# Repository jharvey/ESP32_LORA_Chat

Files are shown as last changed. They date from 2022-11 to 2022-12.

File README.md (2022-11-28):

# ESP32_LORA_Chat </br>
Redesign of Armachat hardware using KICAD and JLCPCB </br>
<hr />
The orginal Armachat from Peter Misenko's work at [bobricius/Armachat-circuitpython](https://github.com/bobricius/Armachat-circuitpython).</br>
This is a ESP32 with working EInk display project, which may be a useful reference https://github.com/Uspizig/EinkKeyboard</br>
 </br>
This is a redesign of bobricius/Armachat hardware to include: </br>
- ESP32 core processor </br>
- E-Ink display for lower power consumpiton </br>
- LORA communications </br>
- 18650 battery </br>
- KICAD </br>
 </br>
 
 front | back | PCB
--- | --- | ---
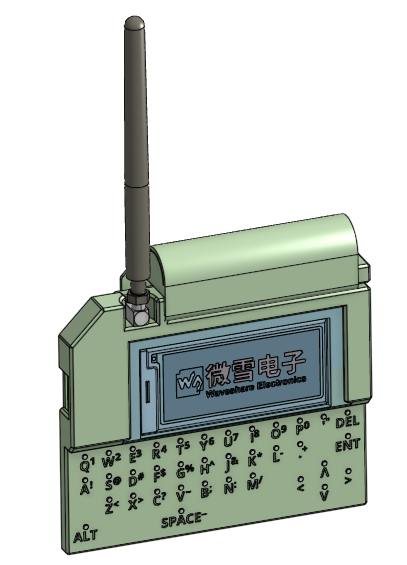
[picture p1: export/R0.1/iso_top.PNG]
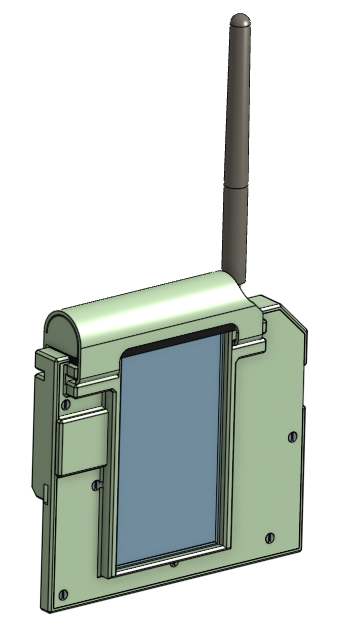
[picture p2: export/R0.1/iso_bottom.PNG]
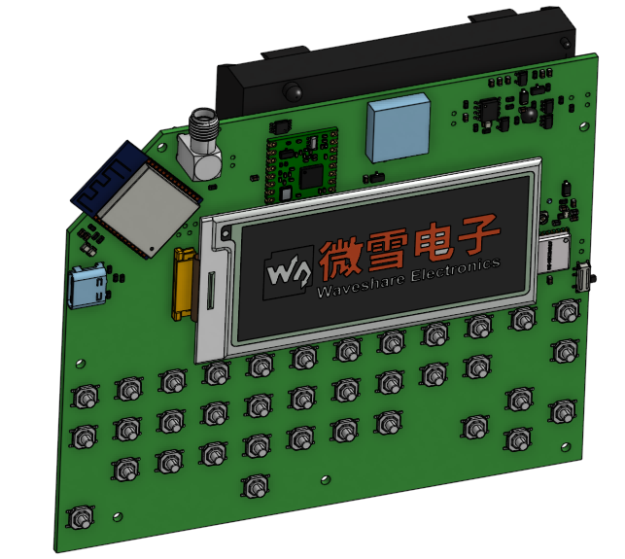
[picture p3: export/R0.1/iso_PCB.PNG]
 |  | 
 </br>
3D model for enclosure found here </br>
https://cad.onshape.com/documents/2eca9b71ceb843e60ebed659/w/deaed59ddef0917efb45d1fe/e/0c98206fb1ddff68e078d781

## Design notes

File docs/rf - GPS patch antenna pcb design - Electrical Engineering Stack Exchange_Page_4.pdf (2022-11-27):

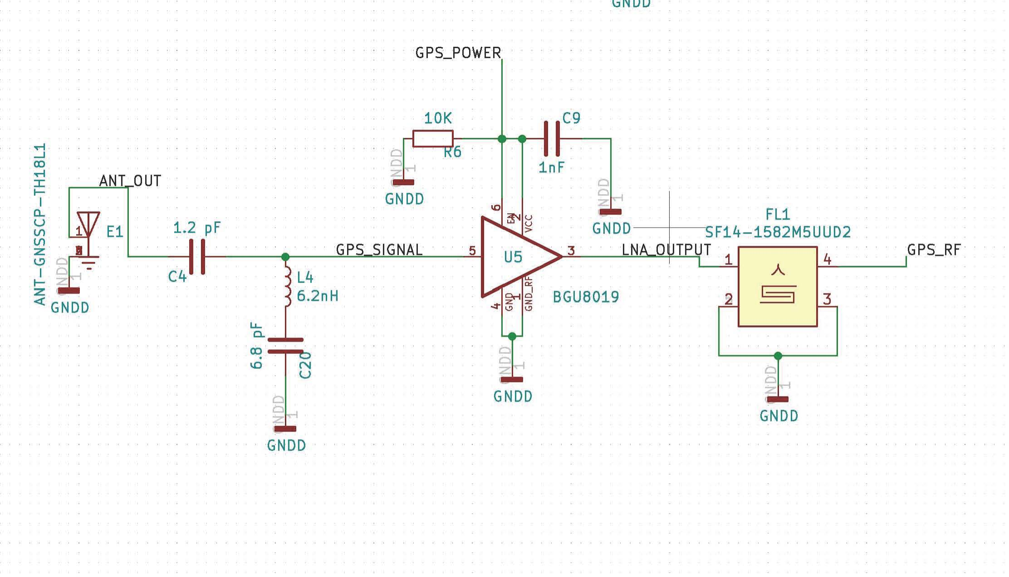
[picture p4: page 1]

..-i
--'
to
..-i
:r:
l-

ANT OUT
I
a..
u
1Il
1Il
Z
<.!l

~7 E1 ....=.c

I
I-
z

I
° -

<G NDD

1.2 pF

C4

'-'-
D..
. . | to .
| <D

GPS POWER -

10K
rl . b 1"<6

0..-i

## ii .. GNDD

'"
r-....~ u
u
>
GPS SIGNAL | 5 | U5
L4
~~ ~
6.2nH | J ... :3 | z
'"

b
N
U | t b | GNDD

t GNDD

lo ~ UU

C9

1nF

0
oM
ii .. | FL1
GNDD | SF14-15B2M5UUD2
:3 | LNA 0 UTPUT 1 | 4 | I A
BGUB019 | ~ | I | I | rl-

b
b.,-i
ii. GNDD

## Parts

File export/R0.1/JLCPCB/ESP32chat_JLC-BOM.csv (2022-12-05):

Comment | Designator | Footprint | LCSC
Antenna | AE1 | KICAD_Footprints:KH-GPS181804-WY | C962215
Conn_Coaxial | AE2 | Connector_Coaxial:U.FL_Hirose_U.FL-R-SMT-1_Vertical | C88374
18650 | BT1 | Battery:BatteryHolder_Keystone_1042_1x18650 | C2988620
1u | C1,C3,C6,C10,C15,C22,C23,C25,C26,C27,C28,C29,C30,C31,C32,C38 | Capacitor_SMD:C_0603_1608Metric | C15849
1.2p | C14 | Capacitor_SMD:C_0603_1608Metric | C281768
6.8p | C16 | Capacitor_SMD:C_0603_1608Metric | C1679
1n | C18 | Capacitor_SMD:C_0603_1608Metric | C100040
100n | C2,C8,C11,C13,C17,C21,C24,C33,C37 | Capacitor_SMD:C_0603_1608Metric | C14663
4.7uF | C20,C34 | Capacitor_SMD:C_0603_1608Metric | C162274
220n | C35 | Capacitor_SMD:C_0603_1608Metric | C21120
10u | C4,C5,C7,C9,C12,C19,C36 | Capacitor_SMD:C_0603_1608Metric | C194427
MBR0530 | D1,D2,D3,D4,D5 | Diode_SMD:D_SOD-123 | C77336
TA1661A | FL1 | KICAD_Footprints:TA1661A | C2961690
GRN | GRN1 | LED_SMD:LED_0805_2012Metric | C434432
CONN_021X02_NO_SILK | J1,J2,J3,J6,J7,J9 | Connector_PinHeader_2.54mm:PinHeader_1x02_P2.54mm_Vertical | DNP
CONN_01 | J4,J5 | Connector_Wire:SolderWirePad_1x01_SMD_5x10mm | DNP
Micro_SD_Card_Det | J8 | KICAD_Footprints:microSD_HC_Molex_104031-0811_Modified_for_JLCPCB | C585350
6.2nH | L1 | Inductor_SMD:L_0603_1608Metric | C98083
68uh | L2 | Inductor_SMD:L_Coilcraft_XAL60xx_6.36x6.56mm | C9393
6.8nH | L3 | Inductor_SMD:L_0603_1608Metric | C316305
SYM_Radio_Waves_Small | LOGO1 | Symbol:ESD-Logo_6.6x6mm_SilkScreen | C108781
OSHW-LOGOS | LOGO2 | Symbol:OSHW-Logo2_7.3x6mm_Copper | DNP
ORG | ORG1 | LED_SMD:LED_0805_2012Metric | C84262
Q_PMOS_DGS | Q1 | KICAD_Footprints:SOT-23_Modified_for_JLCPCB | C15127
BSS123 | Q2 | KICAD_Footprints:SOT-23_Modified_for_JLCPCB | C79015
Si1308 | Q3 | KICAD_Footprints:SOT-323_SC-70_Modified_for_JLCPCB | C469327
Q_NPN_BEC | Q4,Q5 | KICAD_Footprints:SOT-23_Modified_for_JLCPCB | C49581
10K | R1,R2,R3,R4,R7,R9,R12,R14,R18,R34,R35,R43,R44 | Resistor_SMD:R_0603_1608Metric | C25804
0R | R10,R15,R16,R20,R21,R25,R26,R27,R28,R29,R30,R31,R32,R33,R36,R37,R39,R40,R41,R42 | Resistor_SMD:R_0603_1608Metric | C21189
100 | R11 | Resistor_SMD:R_0603_1608Metric | C4184
50K | R13,R17 | Resistor_SMD:R_0603_1608Metric | C23162
1K5 | R23,R24 | Resistor_SMD:R_0603_1608Metric | C22843
0R47 | R38 | Resistor_SMD:R_0603_1608Metric | C23411
10K DNP | R45 | Resistor_SMD:R_0603_1608Metric | DNP
22K1 | R47,R48 | Resistor_SMD:R_0603_1608Metric | C3016734
0R | R49,R51,R52 | Resistor_SMD:R_2010_5025Metric | C2907556
5K1 | R5,R19,R50 | Resistor_SMD:R_0603_1608Metric | C23186
1K | R6,R8,R22,R46,R53 | Resistor_SMD:R_0603_1608Metric | C21190
RED | RED1 | LED_SMD:LED_0805_2012Metric | C84256
PB22 | S1,S2,S3,S4,S5,S6,S7,S8,S9,S10,S11,S12,S13,S14,S15,S16,S17,S18,S19,S20,S21,S22,S23,S24,S25,S26,S27,S28,S29,S30,S31,S32,S33,S34,S35,S36 | KICAD_Footprints:TS-1187A-C-G-B | C318886
Solar_Cell | SC1 |  | DNP
SW_DIP_x01 | SW1 | Button_Switch_SMD:SW_SPDT_PCM12 | C109335
SW_Push_DPDT | SW2 | Button_Switch_THT:SW_E-Switch_EG1271_DPDT | C136144
CONN_01 | TP1,TP2,TP3,TP4,TP5,TP6,TP7,TP8,TP9,TP10,TP11,TP12,TP13,TP14,TP15,TP16,TP17,TP18,TP19,TP20,TP21,TP22,TP23,TP24,TP25,TP26,TP27,TP28,TP29,TP30,TP31,TP32,TP33,TP34,TP35,TP36,TP37,TP38,TP39,TP40,TP41,TP42,TP43,TP44,TP45,TP46 | KICAD_Footprints:TST_x01_P2.54mm_Vertical | DNP
MCP73831T-2ACI/OT | U1 | KICAD_Footprints:SOT-23-5_Modified_for_JLCPCB-5 | C424093
MOUNTINGHOLE2.0 | U10,U11,U12,U13,U14,U15,U16,U17 | MountingHole:MountingHole_2.2mm_M2_DIN965_Pad | DNP
BGU8019 | U18 | KICAD_Footprints:XSON6 | C3190009
BUZZER | U19 | KICAD_Footprints:FS-1340 | C482342
TP4056 | U2 | KICAD_Footprints:SOIC-8-1EP_3.9x4.9mm_P1.27mm_EP2.29x3mm_Therm_Modified_for_JLCPCB | C16581
LM75B | U20 | KICAD_Footprints:MSOP-8_3x3mm_P0.65mm_Modified_for_JLCPCB | C2837470
ATGM336H-5N31 | U21 | KICAD_Footprints:ATGM336H-5N | C90770
QMC5883L | U22 | Package_LGA:LGA-16_3x3mm_P0.5mm | C976032
FPCConn | U23 | KICAD_Footprints:TE_2-1734839-4_1x24-1MP_P0.5mm_Horizontal_2 | C11092
CP2102N-Axx-xQFN28 | U24 | Package_DFN_QFN:QFN-28-1EP_5x5mm_P0.5mm_EP3.35x3.35mm | C964632
ESP32 | U3 | KICAD_Footprints:ESP32-S3-WROOM-1 | C2913204
FS8205A | U4 | KICAD_Footprints:TSSOP-8_4.4x3mm_P0.65mm_Modified_for_JLCPCB | C16052
DW01 | U5 | KICAD_Footprints:SOT-23-6_Modified_for_JLCPCB | C351410
RT9013 | U6 | KICAD_Footprints:SOT-23-5_Modified_for_JLCPCB | C47773
RFM69HCW | U7 | KICAD_Footprints:RFM69HCW | C2844473
tp4056_KoreanHropartsElecTYPE-C-31-M-12 | U8,U25 | KICAD_Footprints:USB-C_SMD-TYPE-C-31-M-12 | C134092
PCA9555PW | U9 | KICAD_Footprints:TSSOP-24_4.4x7.8mm_P0.65mm_Modified_for_JLCPCB | C128392
uFL | X1 | KICAD_Footprints:SMA_Molex_73251-2200_Horizontal_Modified_for_JLCPCB | C411575

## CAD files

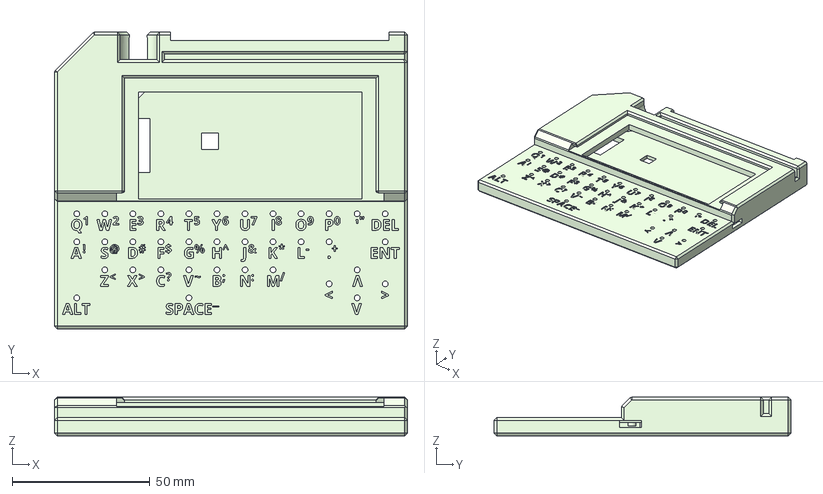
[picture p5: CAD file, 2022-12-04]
export/R0.1/JLCPCB/top_enclosure.step
127.9 x 107.6 x 14.1 mm

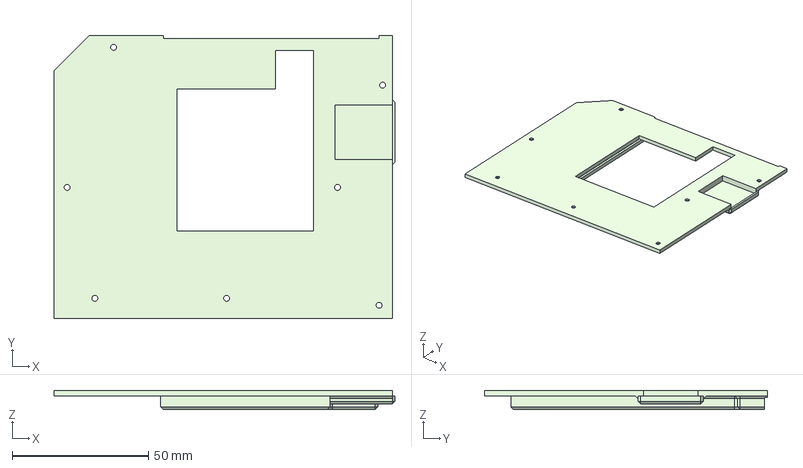
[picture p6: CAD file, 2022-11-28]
export/R0.1/JLCPCB/bottom_enclosure.step
124.9 x 103.6 x 7.00 mm

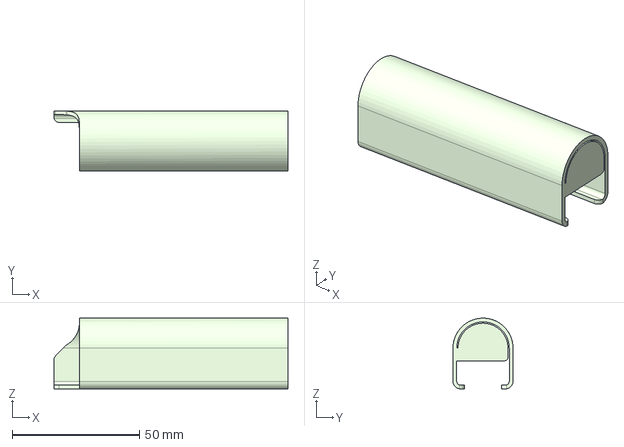
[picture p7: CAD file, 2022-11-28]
export/R0.1/JLCPCB/Bat_Cover.step
92.0 x 23.7 x 27.8 mm

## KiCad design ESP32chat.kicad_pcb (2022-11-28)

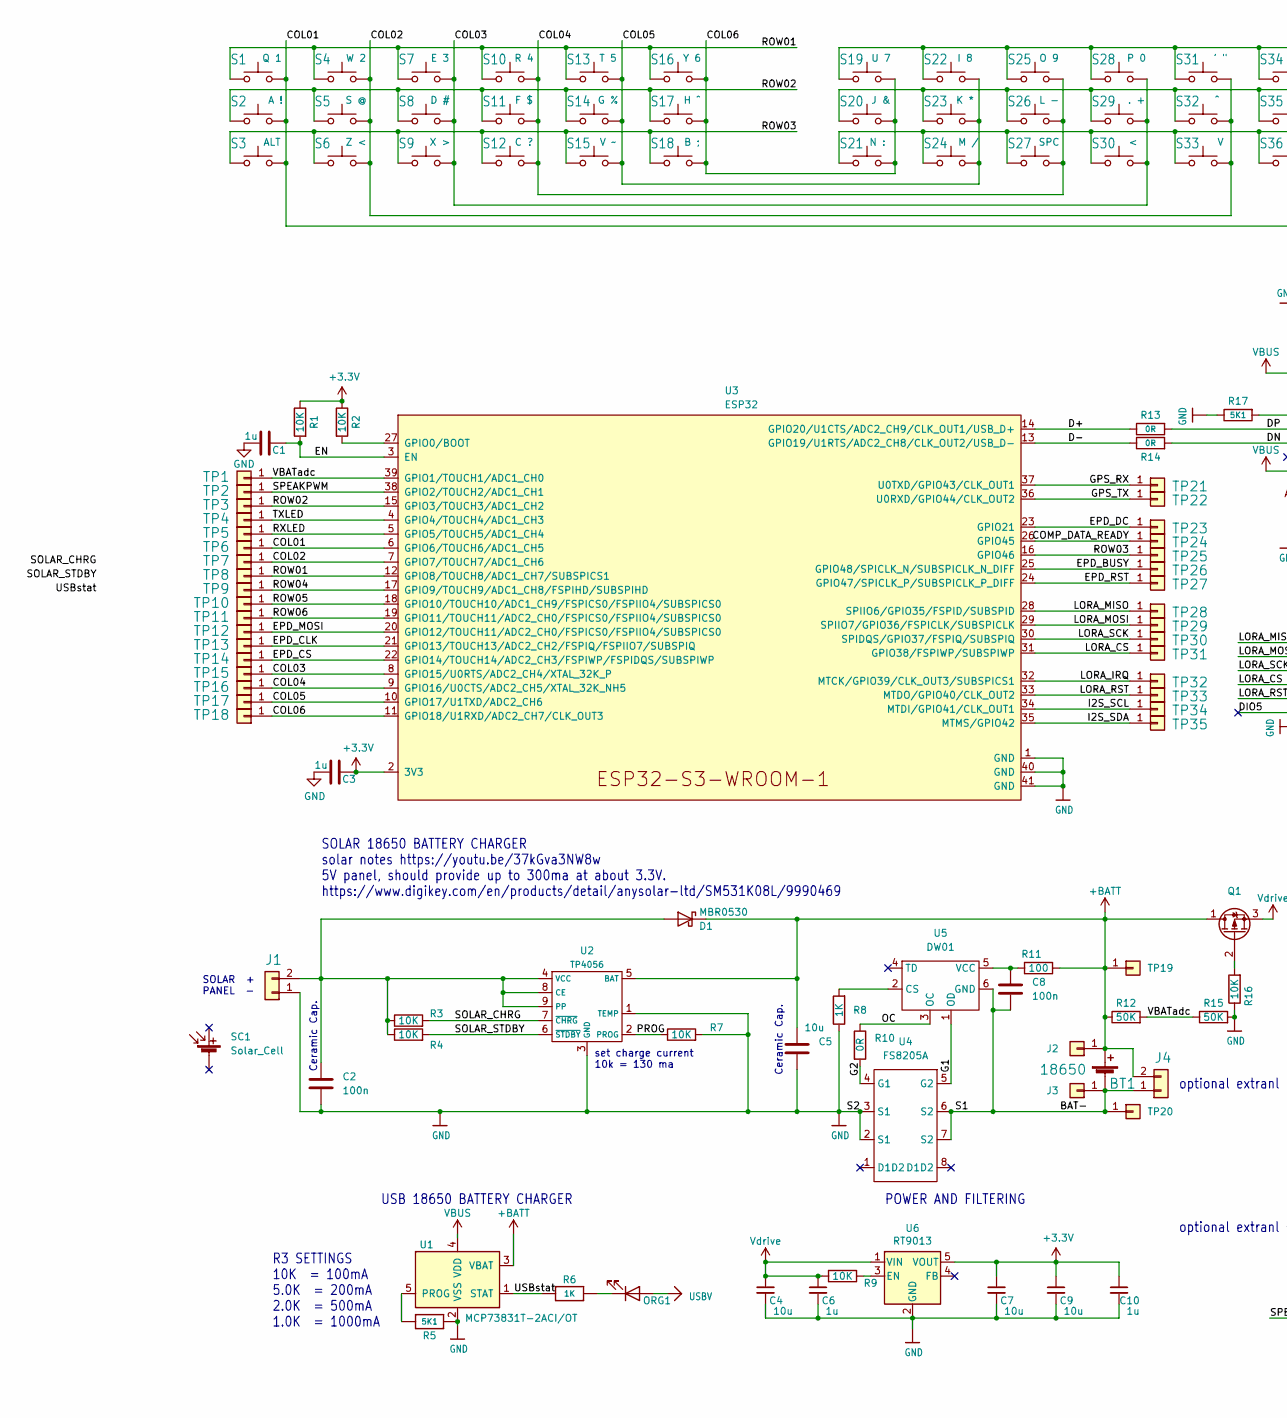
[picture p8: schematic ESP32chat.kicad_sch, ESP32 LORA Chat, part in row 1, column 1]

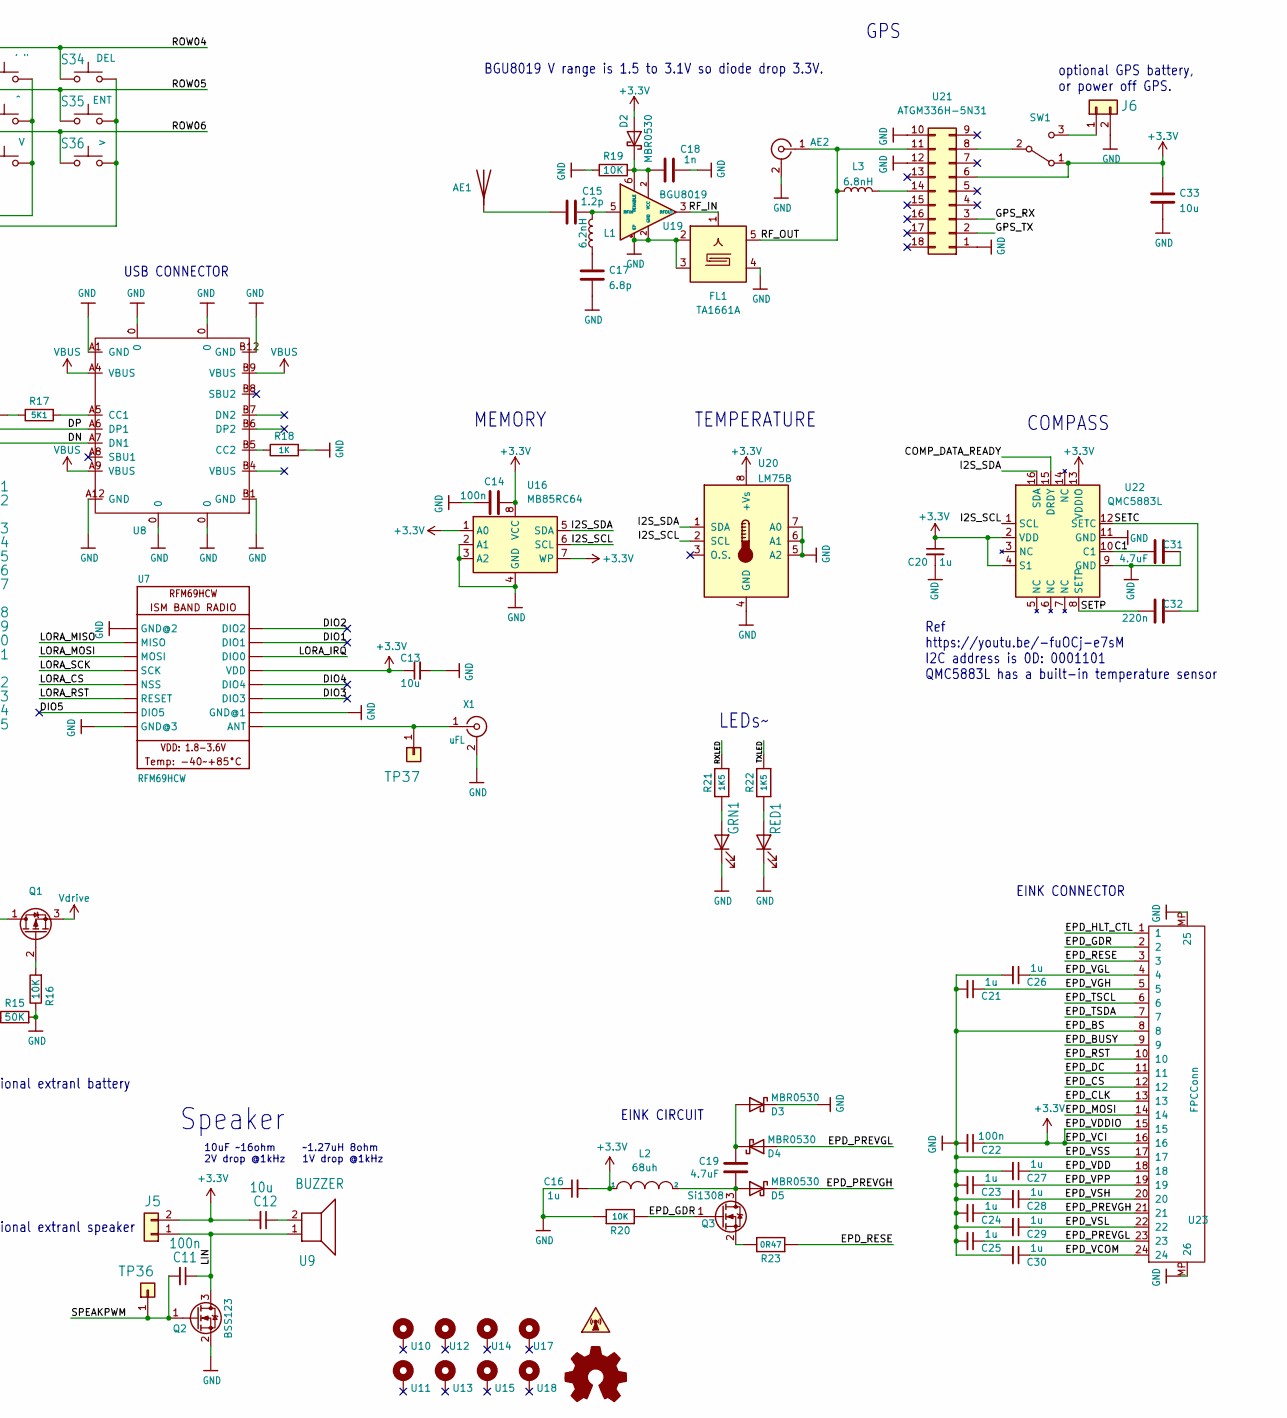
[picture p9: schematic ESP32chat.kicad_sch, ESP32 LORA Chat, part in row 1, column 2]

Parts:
AE1: Antenna; KH-GPS181804-WY; LCSC C962215
AE2: Conn_Coaxial; U.FL_Hirose_U.FL-R-SMT-1_Vertical; LCSC C88374
BT1: 18650; BatteryHolder_Keystone_1042_1x18650; LCSC C2988620
C1, C3, C6, C10, C16, C20, C21, C23, C24, C25, C26, C27, C28, C29, C30: 1u; C_0603_1608Metric; LCSC C15849
C2, C8, C11, C14, C22: 100n; C_0603_1608Metric; LCSC C14663
C4, C5, C7, C9, C12, C13, C33: 10u; C_0603_1608Metric; LCSC C194427
C15: 1.2p; C_0603_1608Metric; LCSC C281768
C17: 6.8p; C_0603_1608Metric; LCSC C1679
C18: 1n; C_0603_1608Metric; LCSC C100040
C19, C31: 4.7uF; C_0603_1608Metric; LCSC C162274
C32: 220n; C_0603_1608Metric; LCSC C21120
D1, D2, D3, D4, D5: MBR0530; D_SOD-123; LCSC C77336
FL1: TA1661A; LCSC C2961690
GRN1: GRN; LED_0805_2012Metric; LCSC C434432
J1, J4, J5, J6: CONN_021X02_NO_SILK; PinHeader_1x02_P2.54mm_Vertical; LCSC DNP
J2, J3: CONN_01; SolderWirePad_1x01_SMD_5x10mm; LCSC DNP
L1: 6.2nH; L_0603_1608Metric; LCSC C98083
L2: 68uh; L_Coilcraft_XAL60xx_6.36x6.56mm; LCSC C9393
L3: 6.8nH; L_0603_1608Metric; LCSC C316305
LOGO1: SYM_Radio_Waves_Small; ESD-Logo_6.6x6mm_SilkScreen; LCSC C108781
LOGO2: OSHW-LOGOS; OSHW-Logo2_7.3x6mm_Copper; LCSC DNP
ORG1: ORG; LED_0805_2012Metric; LCSC C84262
Q1: Q_PMOS_DGS; SOT-23; LCSC C15127
Q2: BSS123; SOT-23; LCSC C79015
Q3: Si1308; SOT-323_SC-70; LCSC C469327
R1, R2, R3, R4, R7, R9, R16, R19, R20: 10K; R_0603_1608Metric; LCSC C25804
R5, R17: 5K1; R_0603_1608Metric; LCSC C23186
R6, R8, R18: 1K; R_0603_1608Metric; LCSC C21190
R10, R13, R14: 0R; R_0603_1608Metric; LCSC C21189
R11: 100; R_0603_1608Metric; LCSC C4184
R12, R15: 50K; R_0603_1608Metric; LCSC C23162
R21, R22: 1K5; R_0603_1608Metric; LCSC C22843
R23: 0R47; R_0603_1608Metric; LCSC C23411
RED1: RED; LED_0805_2012Metric; LCSC C84256
S1, S2, S3, S4, S5, S6, S7, S8, S9, S10, S11, S12, S13, S14, S15, S16, S17, S18, S19, S20, S21, S22, S23, S24, S25, S26, S27, S28, S29, S30, S31, S32, S33, S34, S35, S36: PB22; TS-1187A-C-G-B; LCSC C318886
SC1: Solar_Cell; DIGIKEY SM531K08L-ND
SW1: SW_DIP_x01; SW_SPDT_PCM12; LCSC C109335
TP1, TP2, TP3, TP4, TP5, TP6, TP7, TP8, TP9, TP10, TP11, TP12, TP13, TP14, TP15, TP16, TP17, TP18, TP19, TP20, TP21, TP22, TP23, TP24, TP25, TP26, TP27, TP28, TP29, TP30, TP31, TP32, TP33, TP34, TP35, TP36, TP37: CONN_01; TST_x01_P2.54mm_Vertical; LCSC DNP
U1: MCP73831T-2ACI/OT; SOT-23-5; LCSC C424093
U2: TP4056; SOIC-8-1EP_3.9x4.9mm_P1.27mm_EP2.29x3mm_ThermalVias; LCSC C16581
U3: ESP32; ESP32-S3-WROOM-1; LCSC C2913199
U4: FS8205A; TSSOP-8_4.4x3mm_P0.65mm; LCSC C16052
U5: DW01; SOT-23-6; LCSC C351410
U6: RT9013; SOT-23-5; LCSC C47773
U7: RFM69HCW; LCSC C2844473
U8: tp4056_KoreanHropartsElecTYPE-C-31-M-12; USB-C_SMD-TYPE-C-31-M-12; LCSC C134092
U9: BUZZER; FS-1340; LCSC C482342
U10, U11, U12, U13, U14, U15, U17, U18: MOUNTINGHOLE2.0; MountingHole_2.2mm_M2_DIN965_Pad; LCSC DNP
U16: MB85RC64; SOP-8_3.9x4.9mm_P1.27mm; LCSC C189804
U19: BGU8019; XSON6; LCSC C3190009
U20: LM75B; MSOP-8_3x3mm_P0.65mm; LCSC C2837470
U21: ATGM336H-5N31; ATGM336H-5N; LCSC C90770
U22: QMC5883L; LGA-16_3x3mm_P0.5mm; LCSC C976032
U23: FPCConn; TE_2-1734839-4_1x24-1MP_P0.5mm_Horizontal_2; LCSC C11092
X1: uFL; SMA_Molex_73251-2200_Horizontal; LCSC C411575

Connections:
+3.3V: C3.2, C7.1, C9.1, C10.1, C12.2, C13.1, C14.2, C16.2, C20.1, C22.1, C33.1, D2.2 (A), J5.2, L2.1, R1.1, R2.1, SW1.1 (A), U3.2 (3V3), U6.5 (VOUT), U7.5 (VDD), U16.1 (A0), U16.7 (WP), U16.8 (VCC), U20.8 (+Vs), U21.6, U22.2 (VDD), U22.4 (S1), U22.13 (VDDIO), U23.15, U23.16
+BATT: BT1.1 (+), C5.1, D1.1 (K), J2.1, J4.2, Q1.1 (D), R11.1, R12.1, TP19.1, U1.3 (VBAT), U2.5 (BAT)
/BAT-: BT1.2 (-), C8.2, J3.1, J4.1, TP20.1, U4.6 (S2), U4.7 (S2), U5.6 (GND)
/C1: C31.2, U22.10 (C1)
/COL01: S1.2, S2.2, S3.2, S34.2, S35.2, S36.2, TP6.1, U3.6 (GPIO6/TOUCH6/ADC1_CH5)
/COL02: S4.2, S5.2, S6.2, S31.2, S32.2, S33.2, TP7.1, U3.7 (GPIO7/TOUCH7/ADC1_CH6)
/COL03: S7.2, S8.2, S9.2, S28.2, S29.2, S30.2, TP15.1, U3.8 (GPIO15/U0RTS/ADC2_CH4/XTAL_32K_P)
/COL04: S10.2, S11.2, S12.2, S25.2, S26.2, S27.2, TP16.1, U3.9 (GPIO16/U0CTS/ADC2_CH5/XTAL_32K_NH5)
/COL05: S13.2, S14.2, S15.2, S22.2, S23.2, S24.2, TP17.1, U3.10 (GPIO17/U1TXD/ADC2_CH6)
/COL06: S16.2, S17.2, S18.2, S19.2, S20.2, S21.2, TP18.1, U3.11 (GPIO18/U1RXD/ADC2_CH7/CLK_OUT3)
/COMP_DATA_READY: TP24.1, U3.26 (GPIO45), U22.15 (DRDY)
/D+: R13.1, U3.14 (GPIO20/U1CTS/ADC2_CH9/CLK_OUT1/USB_D+)
/D-: R14.1, U3.13 (GPIO19/U1RTS/ADC2_CH8/CLK_OUT2/USB_D-)
/DIO1: U7.7 (DIO1)
/DIO2: U7.8 (DIO2)
/DIO3: U7.3 (DIO3)
/DIO4: U7.4 (DIO4)
/DIO5: U7.15 (DIO5)
/DN: R14.2, U8.A7 (DN1)
/DP: R13.2, U8.A6 (DP1)
/EN: C1.2, R1.2, U3.3 (EN)
/EPD_BUSY: TP26.1, U3.25 (GPIO48/SPICLK_N/SUBSPICLK_N_DIFF), U23.9
/EPD_CLK: TP13.1, U3.21 (GPIO13/TOUCH13/ADC2_CH2/FSPIQ/FSPIIO7/S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), U23.13
/EPD_CS: TP14.1, U3.22 (GPIO14/TOUCH14/ADC2_CH3/FSPIWP/FSPIDQS/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), U23.12
/EPD_DC: TP23.1, U3.23 (GPIO21), U23.11
/EPD_GDR: Q3.1 (G), R20.1, U23.2
/EPD_HLT_CTL: U23.1
/EPD_MOSI: TP12.1, U3.20 (GPIO12/TOUCH11/ADC2_CH0/FSPICS0/FSPIIO4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), U23.14
/EPD_PREVGH: C24.1, D5.1 (K), U23.21
/EPD_PREVGL: C25.1, D4.2 (A), U23.23
/EPD_RESE: R23.1, U23.3
/EPD_RST: TP27.1, U3.24 (GPIO47/SPICLK_P/SUBSPICLK_P_DIFF), U23.10
/EPD_TSCL: U23.6
/EPD_TSDA: U23.7
/EPD_VCOM: C30.1, U23.24
/EPD_VDD: C27.1, U23.18
/EPD_VGH: C21.1, U23.5
/EPD_VGL: C26.1, U23.4
/EPD_VPP: C23.1, U23.19
/EPD_VSH: C28.1, U23.20
/EPD_VSL: C29.1, U23.22
/G1: U4.5 (G2), U5.1 (OD)
/G2: R10.2, U4.4 (G1)
/GPS_RX: TP21.1, U3.37 (U0TXD/GPIO43/CLK_OUT1), U21.3
/GPS_TX: TP22.1, U3.36 (U0RXD/GPIO44/CLK_OUT2), U21.2
/I2S_SCL: TP34.1, U3.34 (MTDI/GPIO41/CLK_OUT1), U16.6 (SCL), U20.2 (SCL), U22.1 (SCL)
/I2S_SDA: TP35.1, U3.35 (MTMS/GPIO42), U16.5 (SDA), U20.1 (SDA), U22.16 (SDA)
/LIN: C11.1, J5.1, Q2.3 (D), U9.1
/LORA_CS: TP31.1, U3.31 (GPIO38/FSPIWP/SUBSPIWP), U7.13 (NSS)
/LORA_IRQ: TP32.1, U3.32 (MTCK/GPIO39/CLK_OUT3/SUBSPICS1), U7.6 (DIO0)
/LORA_MISO: TP28.1, U3.28 (SPIIO6/GPIO35/FSPID/SUBSPID), U7.10 (MISO)
/LORA_MOSI: TP29.1, U3.29 (SPIIO7/GPIO36/FSPICLK/SUBSPICLK), U7.11 (MOSI)
/LORA_RST: TP33.1, U3.33 (MTDO/GPIO40/CLK_OUT2), U7.14 (RESET)
/LORA_SCK: TP30.1, U3.30 (SPIDQS/GPIO37/FSPIQ/SUBSPIQ), U7.12 (SCK)
/OC: R10.1, U5.3 (OC)
/PROG: R7.1, U2.2 (PROG)
/RF_IN: FL1.1, U19.3 (RFOUT)
/RF_OUT: AE2.1 (In), FL1.5, L3.1, U21.11
/ROW01: S1.1, S4.1, S7.1, S10.1, S13.1, S16.1, TP8.1, U3.12 (GPIO8/TOUCH8/ADC1_CH7/SUBSPICS1)
/ROW02: S2.1, S5.1, S8.1, S11.1, S14.1, S17.1, TP3.1, U3.15 (GPIO3/TOUCH3/ADC1_CH2)
/ROW03: S3.1, S6.1, S9.1, S12.1, S15.1, S18.1, TP25.1, U3.16 (GPIO46)
/ROW04: S19.1, S22.1, S25.1, S28.1, S31.1, S34.1, TP9.1, U3.17 (GPIO9/TOUCH9/ADC1_CH8/FSPIHD/SUBSPIHD)
/ROW05: S20.1, S23.1, S26.1, S29.1, S32.1, S35.1, TP10.1, U3.18 (GPIO10/TOUCH10/ADC1_CH9/FSPICS0/FSPIIO4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)
/ROW06: S21.1, S24.1, S27.1, S30.1, S33.1, S36.1, TP11.1, U3.19 (GPIO11/TOUCH11/ADC2_CH0/FSPICS0/FSPIIO4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)
/RXLED: R21.1, TP5.1, U3.5 (GPIO5/TOUCH5/ADC1_CH4)
/SETC: C32.1, U22.12 (SETC)
/SETP: C32.2, U22.8 (SETP)
/SOLAR_CHRG: R3.2, U2.7 (~CHRG)
/SOLAR_STDBY: R4.2, U2.6 (~STDBY)
/SPEAKPWM: C11.2, Q2.1 (G), TP2.1, TP36.1, U3.38 (GPIO2/TOUCH2/ADC1_CH1)
/TXLED: R22.1, TP4.1, U3.4 (GPIO4/TOUCH4/ADC1_CH3)
/USBstat: R6.2, U1.1 (STAT)
/VBATadc: R12.2, R15.1, TP1.1, U3.39 (GPIO1/TOUCH1/ADC1_CH0)
unnamed: AE1.1 (A), C15.1
unnamed: C2.1, D1.2 (A), J1.2, R3.1, R4.1, U2.4 (VCC), U2.8 (CE), U2.9 (PP)
unnamed: C8.1, R11.2, U5.5 (VCC)
unnamed: C12.1, U9.2
unnamed: C15.2, L1.2, U19.5 (RFIN)
unnamed: C17.1, L1.1
unnamed: C19.1, D5.2 (A), L2.2, Q3.3 (D)
unnamed: C19.2, D3.2 (A), D4.1 (K)
unnamed: GRN1.2 (A), R21.2
unnamed: J6.1, SW1.3 (C)
unnamed: L3.2, U21.14
unnamed: ORG1.1 (K), R6.1
unnamed: Q1.2 (G), R16.2
unnamed: Q3.2 (S), R23.2
unnamed: R2.2, U3.27 (GPIO0/BOOT)
unnamed: R5.2, U1.5 (PROG)
unnamed: R8.2, U5.2 (CS)
unnamed: R9.1, U6.3 (EN)
unnamed: R17.2, U8.A5 (CC1)
unnamed: R18.1, U8.B5 (CC2)
unnamed: R22.2, RED1.2 (A)
unnamed: SW1.2 (B), U21.8
unnamed: TP37.1, U7.1 (ANT), X1.1 (In)
Vdrive: C4.1, C6.1, Q1.3 (S), R9.2, U6.1 (VIN)

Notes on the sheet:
Speaker
LEDs~~{}
BGU8019 V range is 1.5 to 3.1V so diode drop 3.3V.
COMPASS
EINK CIRCUIT
Ceramic Cap.
EINK CONNECTOR
set charge current 10k = 130 ma
optional GPS battery, or power off GPS.
~1.27uH 8ohm 1V drop @1kHz
Ref https://youtu.be/-fuOCj-e7sM I2C address is 0D: 0001101 QMC5883L has a built-in temperature sensor
10uF ~16ohm 2V drop @1kHz
GPS
USB CONNECTOR
TEMPERATURE
R3 SETTINGS 10K = 100mA 5.0K = 200mA 2.0K = 500mA 1.0K = 1000mA
MEMORY
optional extranl battery
POWER AND FILTERING
SOLAR 18650 BATTERY CHARGER solar notes https://youtu.be/37kGva3NW8w 5V panel, should provide up to 300ma at about 3.3V. https://www.digikey.com/en/products/detail/anysolar-ltd/SM531K08L/9990469
SOLAR + PANEL -
optional extranl speaker
USB 18650 BATTERY CHARGER

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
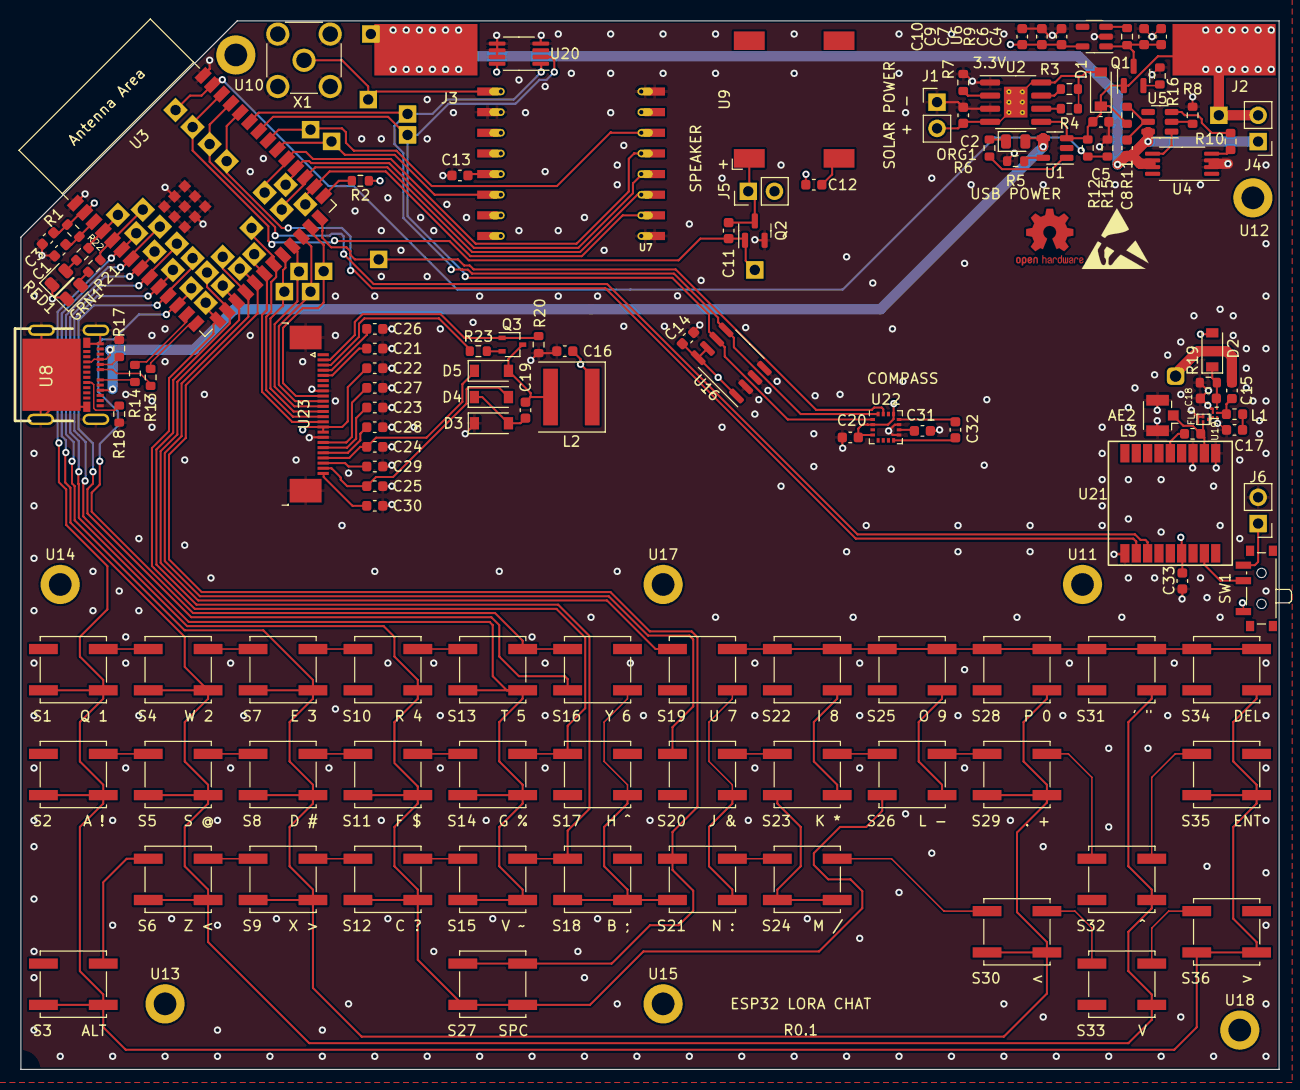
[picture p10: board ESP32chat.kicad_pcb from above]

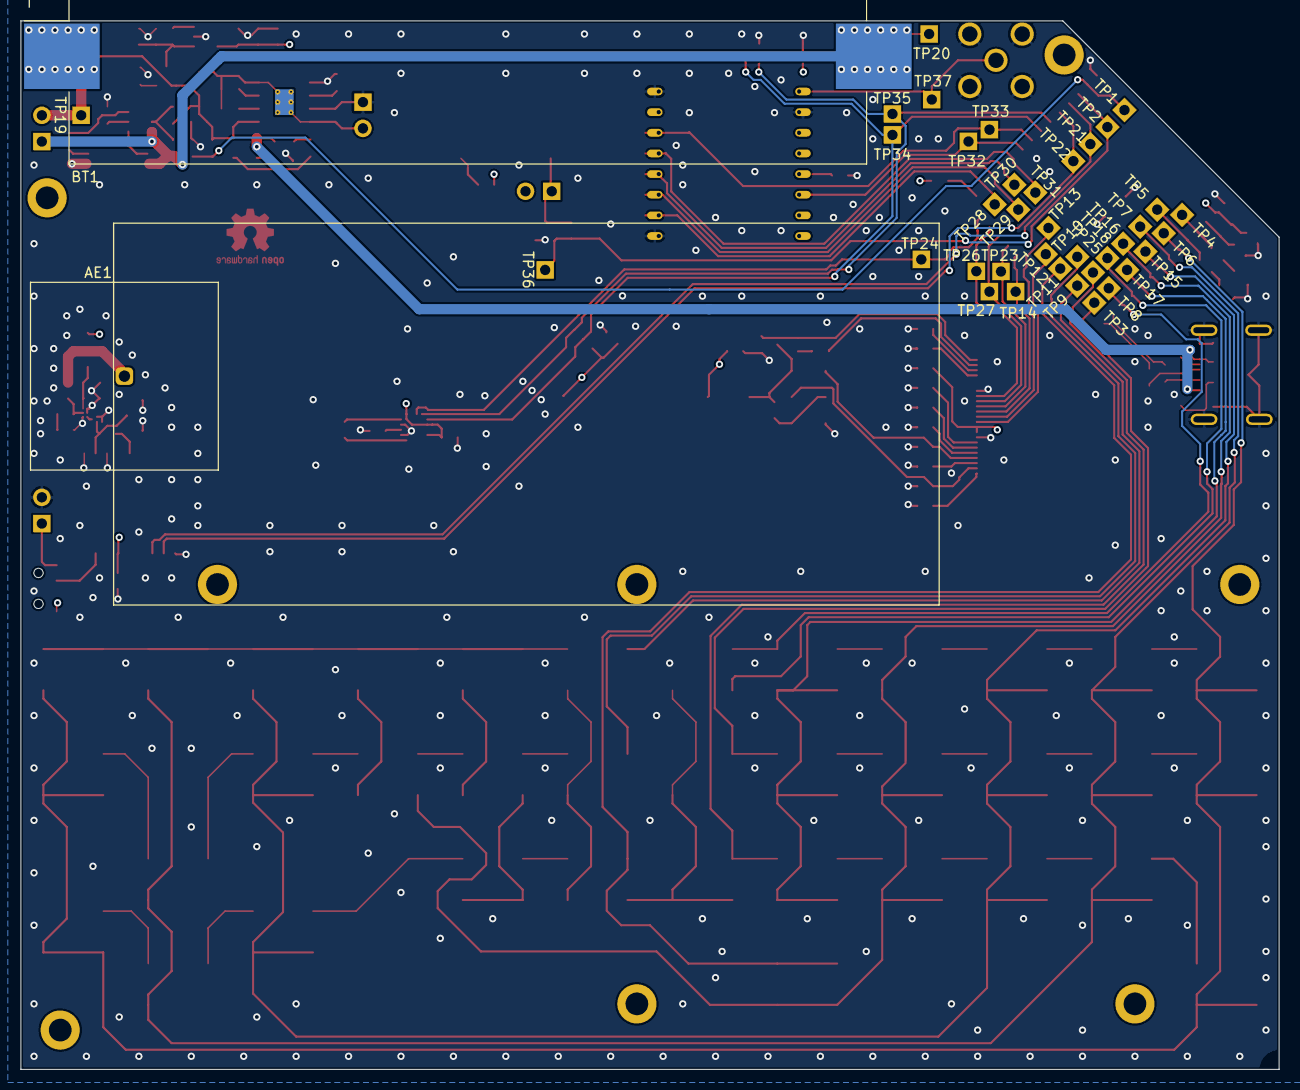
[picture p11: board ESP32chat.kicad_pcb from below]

Board: 4 copper layers, 121.9 x 101.6 mm, 180 parts (39 on the bottom side), 92 nets.

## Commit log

2022-11-22 DRAFT initial check in, still needs lots of work.
    [ESP32chat.kicad_pcb, ESP32chat.kicad_sch]
2022-11-23 DRAFT Still needs silk screen, would be nice to remove errors.
    [ESP32chat.kicad_pcb, ESP32chat.kicad_sch]
2022-11-23 Almost ready for review.
    [ESP32chat.kicad_pcb, ESP32chat.kicad_sch, ESP32chat_JLC-BOM.csv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]
2022-11-24 Added 3D files for a 3D printed enclosure.
    [bottom_enclosure.step, top_enclosure.step]
2022-11-24 Update README.md
    Added link to a working EInk / ESP32 reference design.
2022-11-24 Added PCB ISO graphic
2022-11-24 Update README.md
    Formatting, and added link to 3D model for enclosure.
2022-11-25 DRAFT added solar charging circuit, changed to 6X6 key scanning, 36 buttons with less consumed GPIO. Added temperature sensor to monitor the battery. Added GPS module.
    [ESP32chat.kicad_sch]
2022-11-27 DRAFT laying down copper now, many traces still need to be installed. Checked in for archival purposes.
    [ESP32chat.kicad_pcb, ESP32chat.kicad_sch]
2022-11-27 DRAFT Almost ready for review again. Checking in for archival purposes.
    [ESP32chat.kicad_pcb, ESP32chat.kicad_sch]
2022-11-27 Ready for review.
    [ESP32chat.kicad_pcb, ESP32chat.kicad_sch]
2022-11-28 Some corrections to align with JLCPCB verification, added I2C memory chip.
    [ESP32chat.kicad_pcb, ESP32chat.kicad_sch, ESP32chat_JLC-BOM.csv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]
2022-11-28 Updated kepad layout
    [ESP32chat.kicad_pcb, ESP32chat.kicad_sch]
2022-11-28 added battery cover, updated 3D models for 3D printed enclosure.
    [Bat_Cover.step, bottom_enclosure.step, top_enclosure.step]
2022-11-28 Updated images to show current design changes.
2022-12-04 Added SD memory, Added 2nd USB for 232 initial circuit python programming
    [ESP32chat.kicad_sch, ESP32chat_JLC-BOM.csv, ESP32chat_JLC-BOM_Cost_Reduced.csv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]
2022-12-04 updated the 3D enclosure to accommodate the extra USB port.
    [ESP32chat.kicad_sch, top_enclosure.step]
2022-12-05 Updated BOM
    [ESP32chat.kicad_sch, ESP32chat_JLC-BOM.csv]
